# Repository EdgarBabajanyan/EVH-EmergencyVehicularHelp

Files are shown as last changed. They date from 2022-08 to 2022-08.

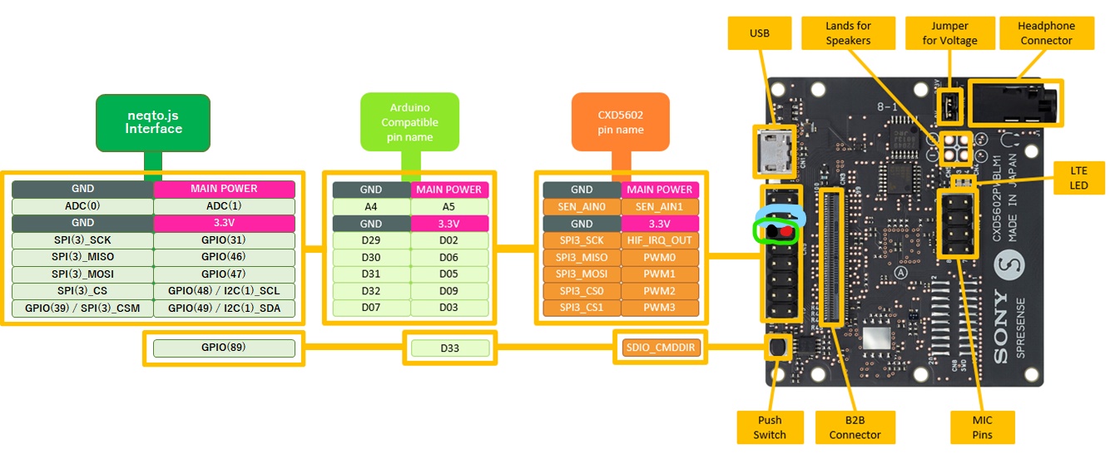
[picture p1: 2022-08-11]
images/WiringforLTEExtension.jpg

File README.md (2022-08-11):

# EVH-EmergencyVehicularHelp
A Hackster.io competition, we designed and developed a device to assist those in bicycle and motorcycle accidents. Using speech recognition, LTE, and other technologies. 

The device's flow is as follows:

User falls off bike --> Device detects irregular position of a bike --> Prompts user asking if he/she is okay --> If positive yes answer --> Device no longer proceeds

If Negative No or Silence detected --> Device asks again and if continous --> Alerts authorities using SMS

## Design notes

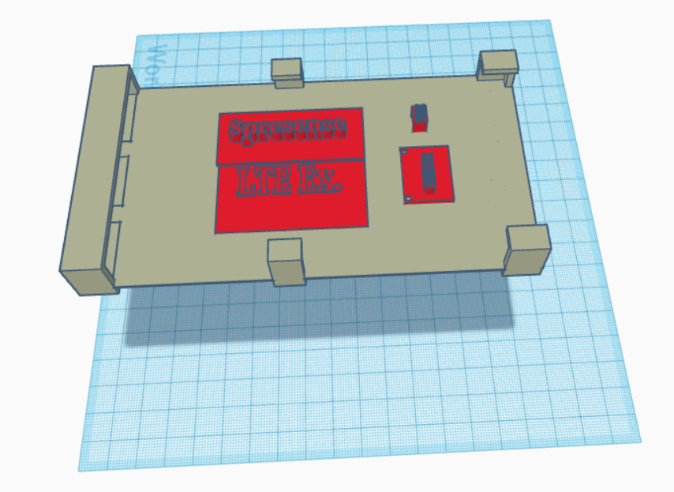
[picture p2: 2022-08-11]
images/prelim_design2.PNG

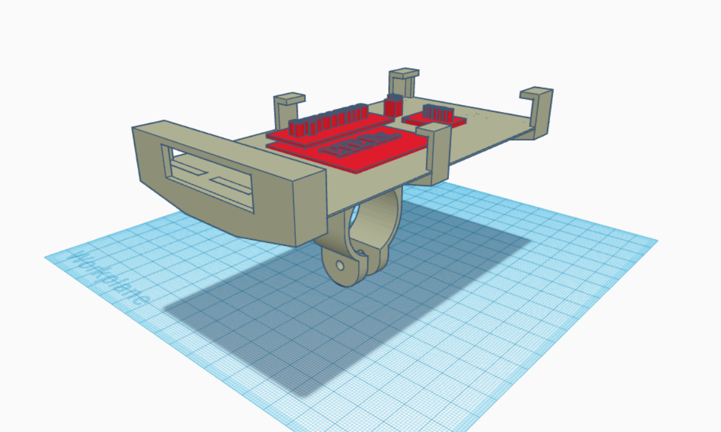
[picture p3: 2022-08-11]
images/prelim_design.PNG

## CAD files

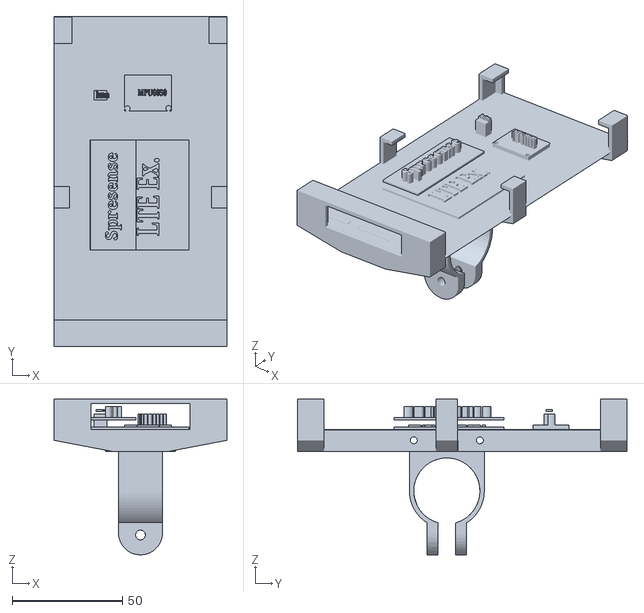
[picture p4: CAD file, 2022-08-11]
3D/3D Model Rev. 1.stl
78.4 x 149.8 x 70.7

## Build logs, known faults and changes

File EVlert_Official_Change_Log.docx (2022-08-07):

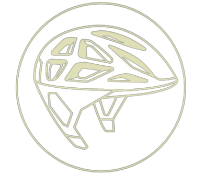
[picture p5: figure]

EVlert Official Change Log

(Debugging and Instructions Log)

Spresense Write Up: https://docs.google.com/document/d/1cHBwsehvIXRTZQCubzxj_toqcKmab2Whq9DGKfKOazg/edit

BOM:

ITEM | COST | TOTAL
Spresense Main Board | 65.00$ | ///////////////////////////////
Spresense LTE Extension | 99.95$ | ///////////////////////////////
Ultrasonic Sensor(s) | 13.50$ | ///////////////////////////////
1.753D Printing PLA Filament | 24.99$ | ///////////////////////////////
Arduino Software | 0.00$ | ///////////////////////////////
/////////////////////////////// | Misc. | 203.44$

Initial Design Choices:


Wiring Diagrams for Reference:

These images contain pins we used for the gyroscope and so on…

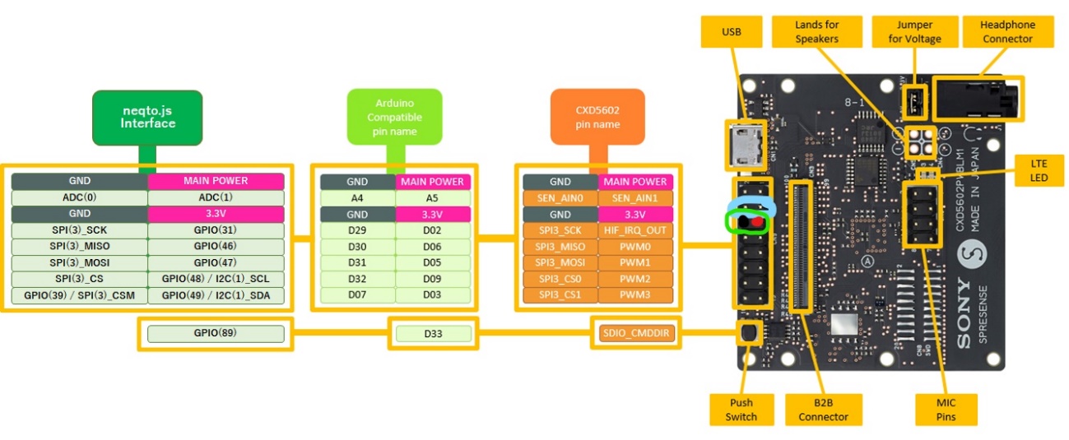
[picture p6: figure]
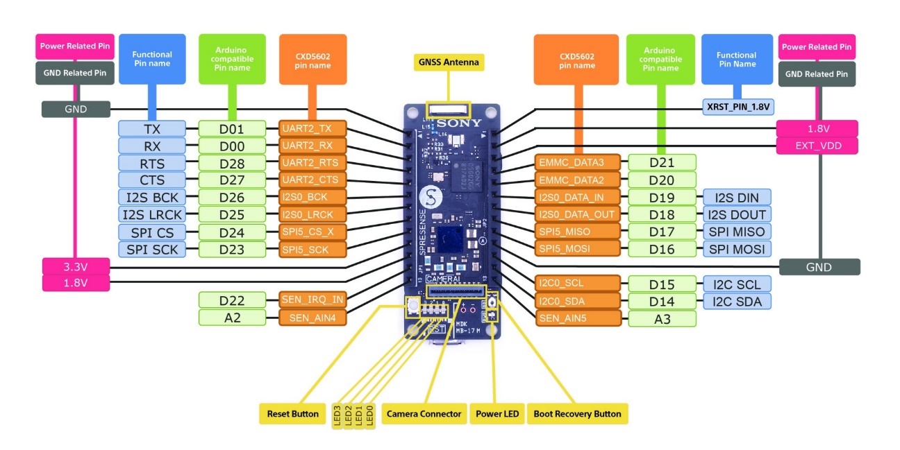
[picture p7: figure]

Debugging in the development of the project:

Error finding and collecting data → MPU 6050 with Spresense and Arduino:

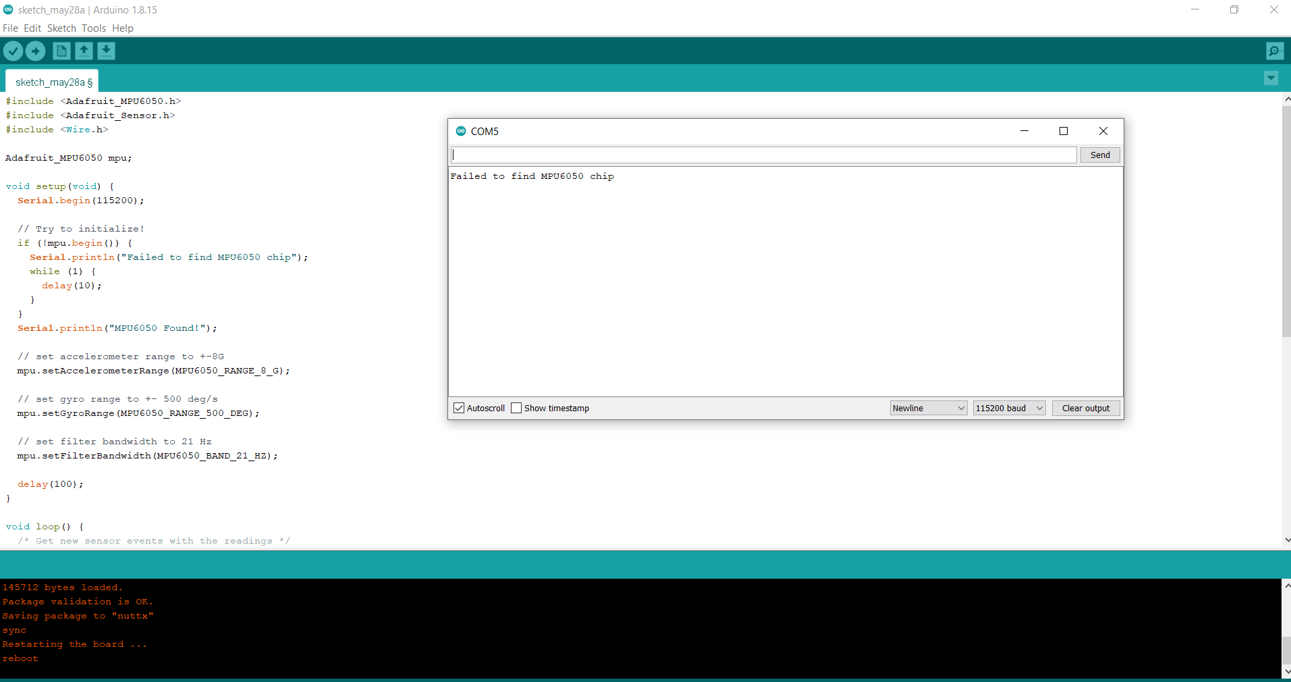
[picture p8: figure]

Attempt Solution 1: We tried to switch SCL and SDA pins on the MPU 6050. Did not work for detection. May have made it worse.

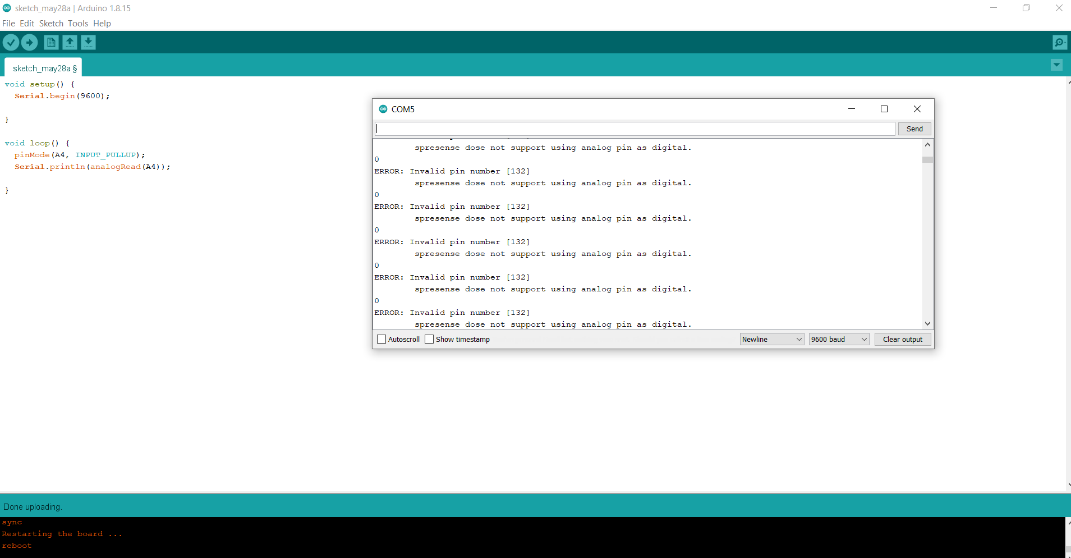
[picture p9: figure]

Attempt Solution 2: Turn on resistor within the Arduino that sends data to A4 pin and it said that it wanted us to use digital pins. Failed to accept pin input MPU6050.

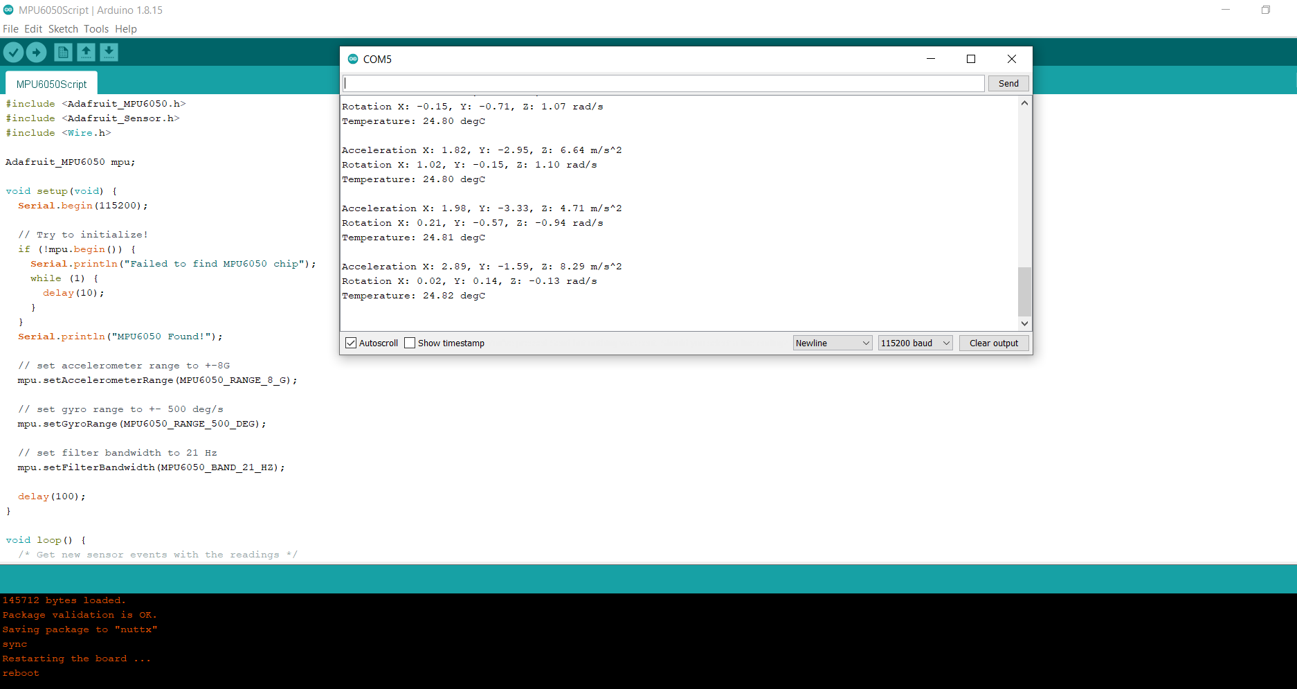
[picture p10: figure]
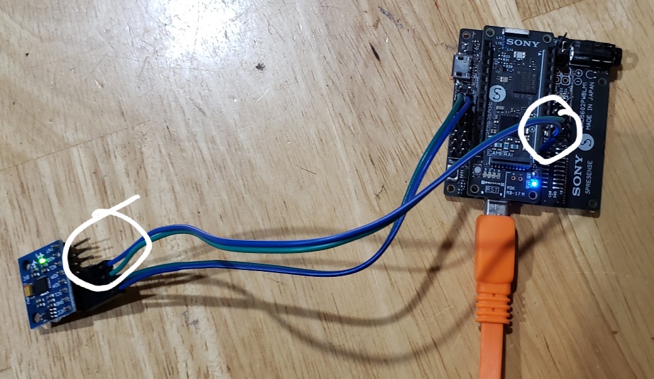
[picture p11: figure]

Attempt Solution 3: The Main Board (Spresense) contains i2c SCL and SDA Pins for Arduino hardware such as the MPU 6050. We swapped our A4 and A5 Pins with the D15 (SCL) and D14 (SDA) pins and we were able to get raw rotation data.

Error looping timed audio prompt:

Attempt 1 Failed: moved the

int err = theAudio->writeFrames(AudioClass::Player0, myFile);

//other error functions

Into its own function, void play().

Attempt 2 Solution:

This failed so the first line above, the int err, needs to be looped because it is constantly sending audio frames to the spresense. So I placed it into a while(1) loop, inside the void play() and broke out of the loop when the file ends, the audio is played except that it didn’t restart when I called play() again the issue must be that once the file ends, I have to restart the file again from the beginning sort of rewinding.

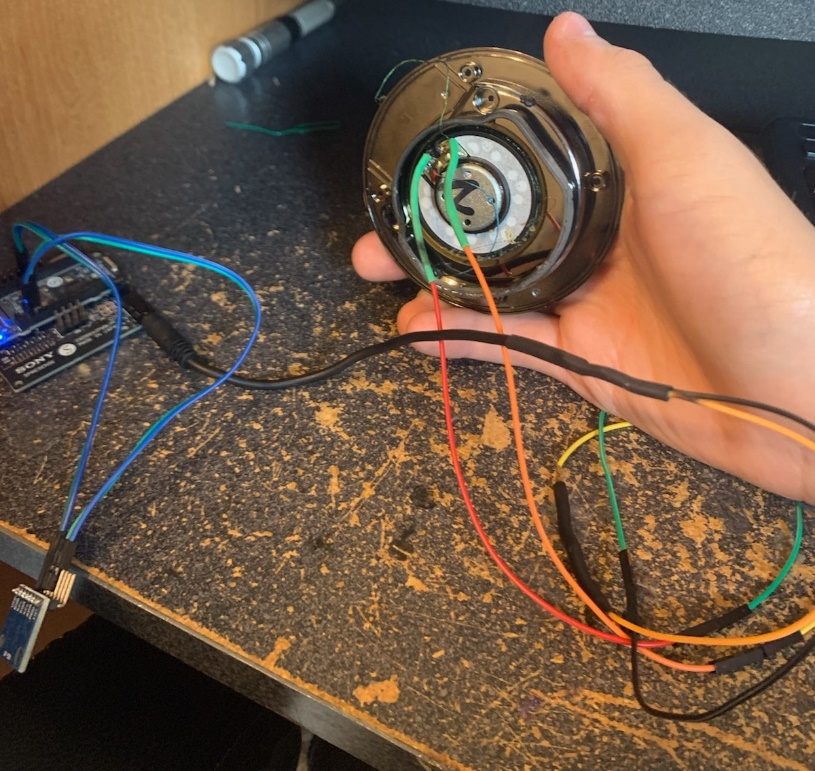
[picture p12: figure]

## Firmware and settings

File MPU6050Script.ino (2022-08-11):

#include <Adafruit_MPU6050.h>
#include <Adafruit_Sensor.h>
#include <Wire.h>
#include <MKRGSM.h>
#include "arduino_secrets.h" 

Adafruit_MPU6050 mpu;

int x = 0;

int y = 0;
bool go = true;
int z = 0;

#include <SDHCI.h>
#include <Audio.h>

SDClass theSD;
AudioClass *theAudio;

File myFile;

bool ErrEnd = false;

// PIN Number for SIM Card
const char PINNUMBER[] = SECRET_PINNUMBER;

lte_initialize sms;

static void audio_attention_cb(const ErrorAttentionParam *atprm)
{
  puts("Attention!");
  
  if (atprm->error_code >= AS_ATTENTION_CODE_WARNING)
    {
      ErrEnd = true;
   }
}

void setup(void) {
  Serial.begin(115200);

//SMS init
  while (!connected) {
    if (gsmAccess.begin(PINNUMBER) == GSM_READY) {
      connected = true;
    } else {
      Serial.println("Not connected");
      delay(1000);
    }
  }

  Serial.println("GSM initialized");

//MPU init
  if (!mpu.begin()) {
    Serial.println("Failed to find MPU6050 chip");
    while (1) {
      delay(10);
    }
  }
  Serial.println("MPU6050 Found!");
  mpu.setAccelerometerRange(MPU6050_RANGE_8_G);
  mpu.setGyroRange(MPU6050_RANGE_500_DEG);
  mpu.setFilterBandwidth(MPU6050_BAND_21_HZ);

//Audio and SD init
  while (!theSD.begin())
    {
      Serial.println("Insert SD card.");
    }

  // start audio system
  theAudio = AudioClass::getInstance();

  theAudio->begin(audio_attention_cb);

  puts("initialization Audio Library");

  theAudio->setRenderingClockMode(AS_CLKMODE_NORMAL);
  theAudio->setPlayerMode(AS_SETPLAYER_OUTPUTDEVICE_SPHP, AS_SP_DRV_MODE_LINEOUT);
  err_t err = theAudio->initPlayer(AudioClass::Player0, AS_CODECTYPE_MP3, "/mnt/sd0/BIN", AS_SAMPLINGRATE_AUTO, AS_CHANNEL_MONO);

  /* Verify player initialize */
  if (err != AUDIOLIB_ECODE_OK)
    {
      printf("Player0 initialize error\n");
      exit(1);
    }

  /* Open file placed on SD card */
  myFile = theSD.open("init.mp3"); //plays an audio saying "initalizing"

  /* Verify file open */
  if (!myFile)
    {
      printf("File open error\n");
      exit(1);
    }
  printf("Open! 0x%08lx\n", (uint32_t)myFile);

  /* Send first frames to be decoded */
  err = theAudio->writeFrames(AudioClass::Player0, myFile);

  if ((err != AUDIOLIB_ECODE_OK) && (err != AUDIOLIB_ECODE_FILEEND))
    {
      printf("File Read Error! =%d\n",err);
      myFile.close();
      exit(1);
    }

  puts("Play!");

  /* Main volume set to -16.0 dB  MAXIMM is 120*/
  theAudio->setVolume(120);
  theAudio->startPlayer(AudioClass::Player0);
}

void loop() {
  
if(x >= 8 || x <= -8){
    Serial.println("Fall detected!");
    go = true;
  }
  while (go) {
    int err = theAudio->writeFrames(AudioClass::Player0, myFile);
    if (err == AUDIOLIB_ECODE_FILEEND) {
      Serial.println("File ended!\n");
      myFile.close();
      myFile = theSD.open("ask_help.mp3"); //prompt begins here
      long int t1 = millis();
      while (digitalRead(A4) == HIGH) {
        long int t2 = millis();
        long int t3 = t1-t2;
        if (t3 >= 20000) {
          //sms send
          sms.beginSMS("2035559081"); //phone numbers must be preloaded
          sms.print("John fell off their bike and has not prevented this message from being sent!"); //message must be preloaded
          sms.endSMS();
          Serial.println("\nCOMPLETE!\n");
        }
      }
      go = false;
    }
    usleep(40000);
  }

  
  /* Get new sensor events with the readings */
  sensors_event_t a, g, temp;
  mpu.getEvent(&a, &g, &temp);

  x = g.gyro.x;
  y = g.gyro.y;
  z = g.gyro.z;
}

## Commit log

2022-08-11 Create stl
2022-08-11 Add files via upload
    Added 3D Model
    [3D Model Rev. 1.stl]
